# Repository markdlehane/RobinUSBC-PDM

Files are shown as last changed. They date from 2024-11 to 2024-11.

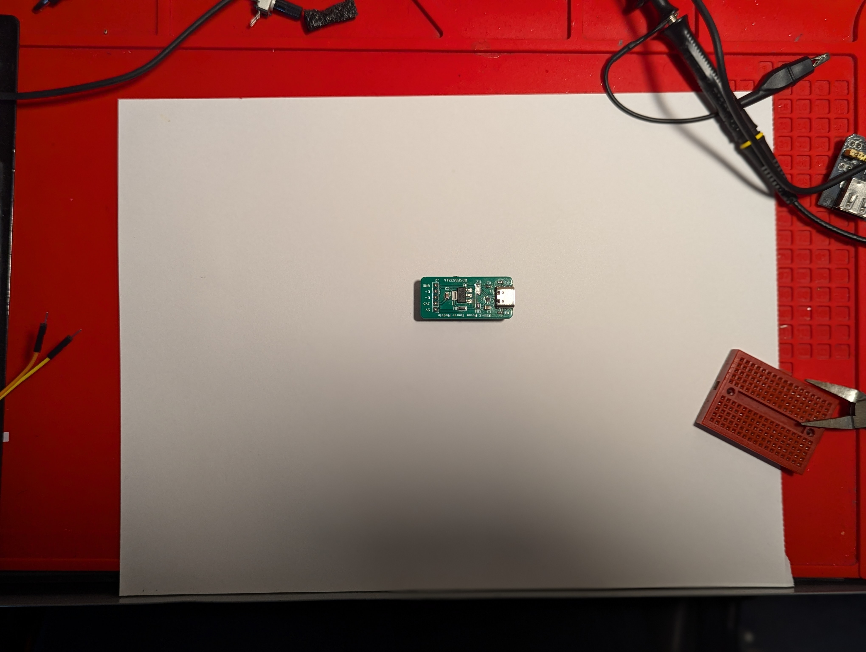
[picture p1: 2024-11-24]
NonGit/Media/PXL_20241114_141916100.PORTRAIT.jpg

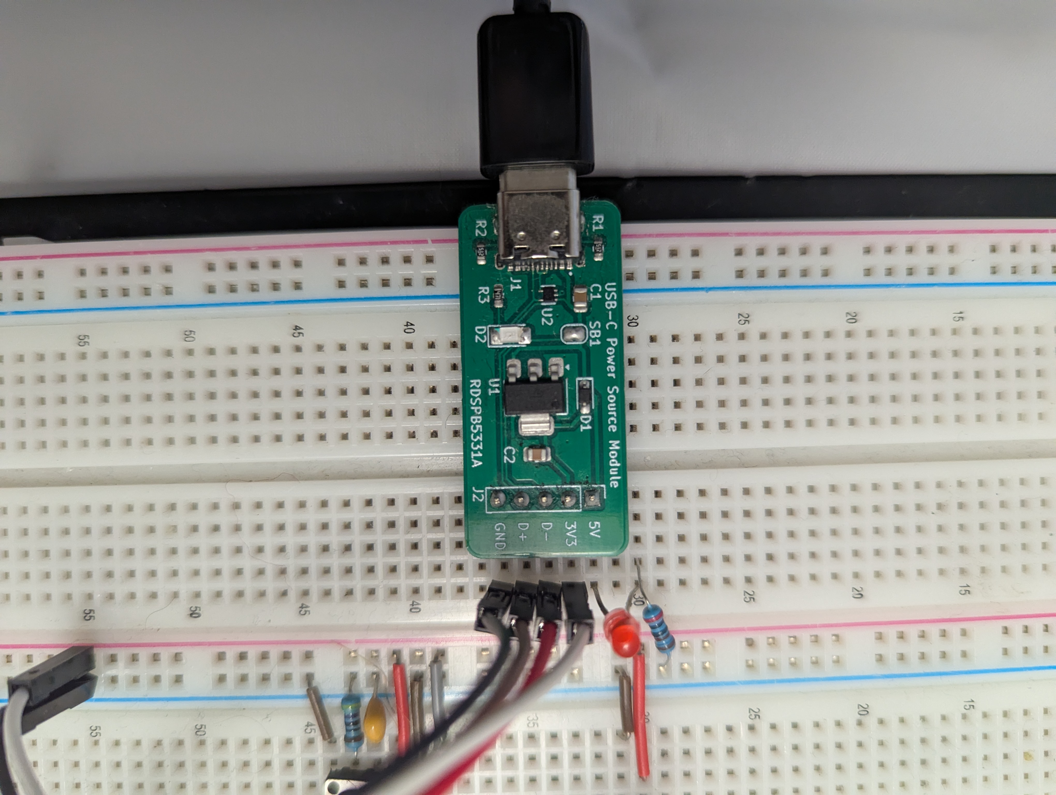
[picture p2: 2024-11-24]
NonGit/Media/PXL_20241124_145701699.RAW-01.COVER.jpg

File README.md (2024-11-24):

# USB-C data and power supply.

## An adaptor that allows connection from a usb power supply or laptop.
RDSPB5331A-Circuit

It's available as a kit or a premade module on [Tindie](https://www.tindie.com/products/36667/).

This adaptor provides 5v & 3.3v @1A from a USB-C connector. It also provides USB D+ and D- pins so that it can be used with a laptop or computer to provide power and data. I developed this board with the assistance of the wonderful people at [PCBWay](https://www.pcbway.com/) who enabled me to take my early design and turn it into a module that I use in every project I make now.  It's a huge time saver and makes the process of connecting my development boards to a laptop, very simple.

## Why did you make it?

I designed this module because I was tired of the standard breadboard power supplies that simply provide 5v or 3.3v from a barrel jack. The old style supplies were limited because, even if I use USB as a supply, I didn't have a data connection. 

## What makes it special?

This module is easy to use on a breadboard, can be integrated directly into a PCB project with a jumper and provides a data pathway to your embedded device. There is a transient voltage suppression device on the board to give added project from voltage spikes as the cable is connected.

## Module design

I designed this board because I have been developing project with ESP32S3 modules. These made a USB data connection immediately available, like many other alternatives, and I wanted to simplify my prototyping and development process through simplification. 

The module is supplied with an [AZ1117I](https://www.diodes.com/assets/Datasheets/AZ1117I.pdf) 3.3v LDO and the 5v is provided directly by the USB-C connection (which uses 2 5k1 1% resistors to negotiate the voltage). There is an LED on the board to indicate that 5v power is connected by this can be disconnected through a solder bridge so that it can be disabled when power must be stricly controlled.

RobinUSBC-back-PSM
RobinUSBC-Front-PSM

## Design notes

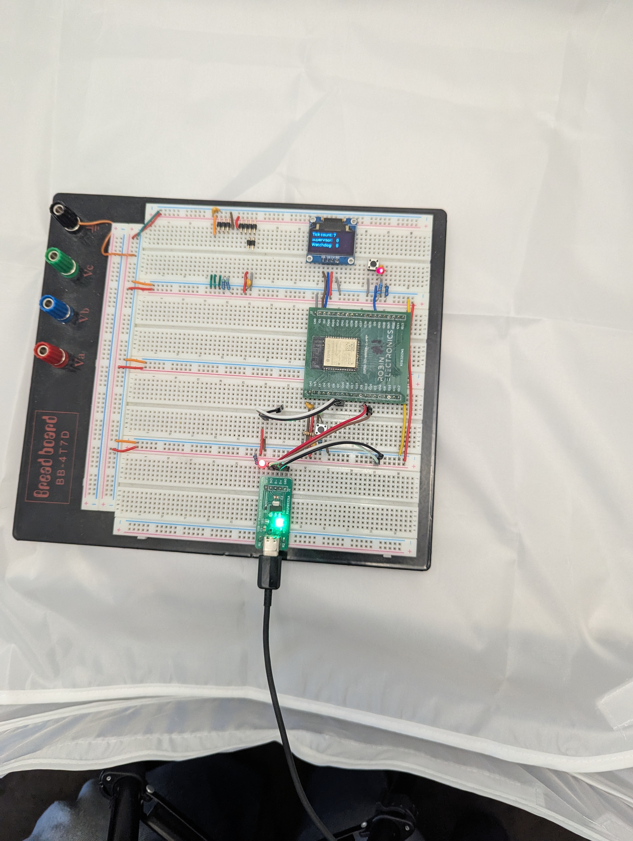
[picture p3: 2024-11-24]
NonGit/Media/PXL_20241124_145235331.RAW-01.COVER.jpg

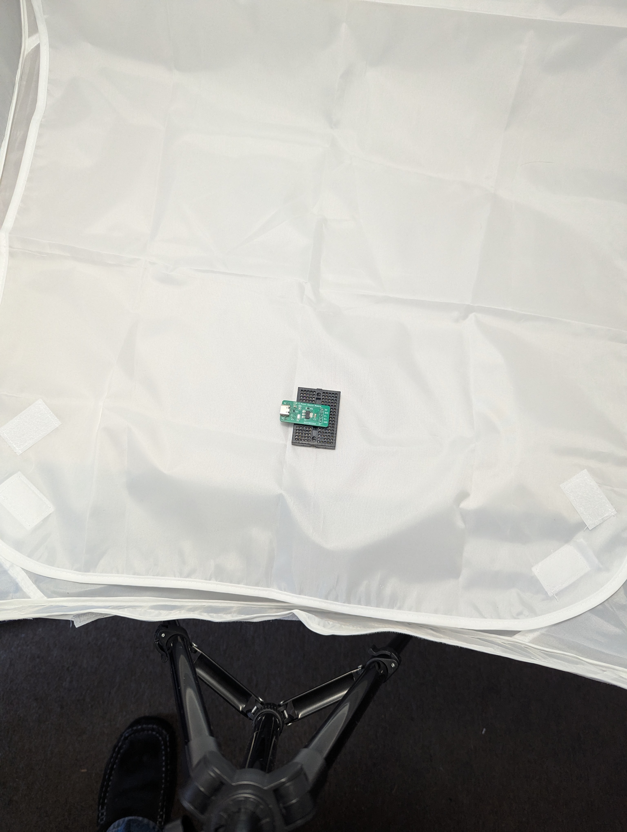
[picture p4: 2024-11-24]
NonGit/Media/PXL_20241124_144541206.RAW-01.COVER.jpg

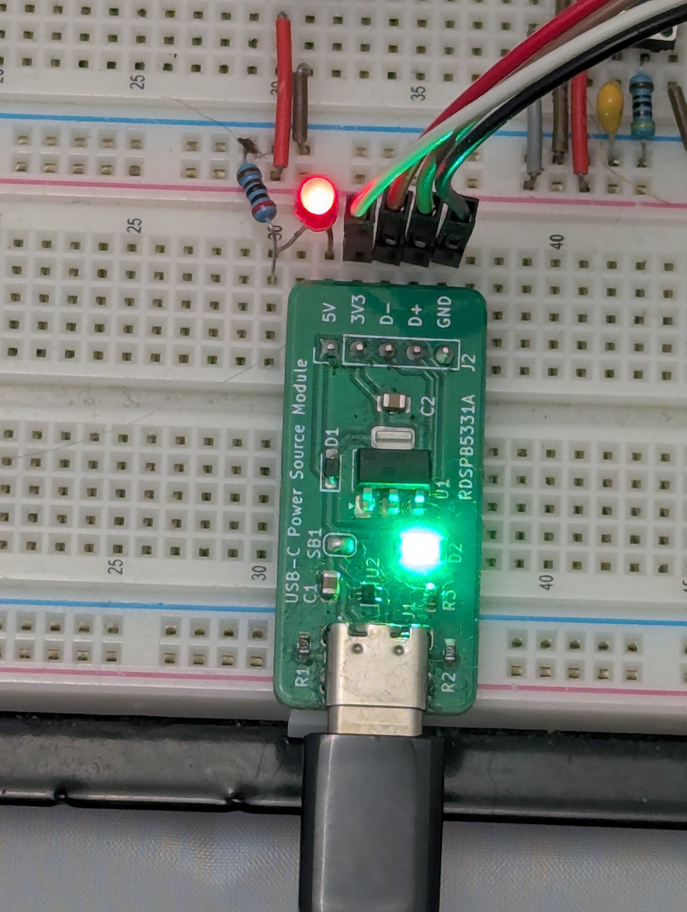
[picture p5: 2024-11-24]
NonGit/Media/PXL_20241124_144733794.RAW-01.COVER.jpg

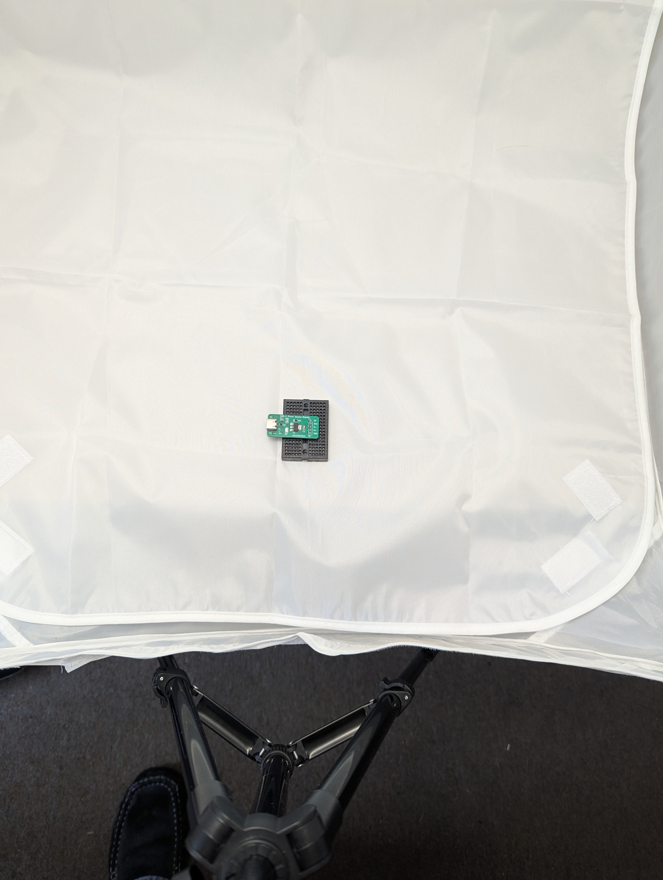
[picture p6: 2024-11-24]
NonGit/Media/PXL_20241124_144548405.RAW-01.COVER.jpg

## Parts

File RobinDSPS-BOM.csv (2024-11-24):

Reference | Value | Description | PartNo | MANUFACTURER
C1 | 10uF | 10 µF ±10% 16V Ceramic Capacitor X7R 0805 (2012 Metric) | CL21B106KOQNNNE | Samsung Electro-Mechanics
U1 | AZ1117IH-3.3TRG1 | 1A 20V Fixed LDO Linear Regulator, 3.3V, SOT-89/SOT-223/TO-220/TO-252/TO-263 | AZ1117IH-3.3TRG1 | Diodes Incorporated
R3 | 1K | 1k 0604 Resistor | RC0603JR-071KL | YAGEO
R1 | 5K1 | 5K1 0603 Resistor | RC0603FR-075K1L | YAGEO
R2 | 5K1 | 5K1 0603 Resistor | RC0603FR-075K1L | YAGEO
C2 | 22uF | CAP CER 22UF 10V X7R 0805 | GRM21BZ71A226ME15L | Murata Electronics
J1 | USB4215-03-A_REVA | CONN RCP USB2.0 TYP C 24P SMD RA | USB4105-GF-A-060 | Global Connector Technology
J2 | Power Output | Connector Header Through Hole 10 position 0.100" (2.54mm) | PH1-10-UA | Adam Tech
D2 | RED LED | LED RED CLEAR 1206 SMD | 150120RS75000 | WÃ¼rth Elektronik
D1 | NSR0530HT1G | Schottky diode, 30V, 500mA | NSR0530HT1G | onsemi
U2 | NUP2114 (TVS) | TVS Protection Diode | NUP2114UPXV5T1G | Diodes Incorporated

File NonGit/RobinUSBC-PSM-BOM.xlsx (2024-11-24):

Robin USBC-PSM Build Notes
Date | 2024-10-17 |  | Specification | 5v & 3.3v output @ up to 1A, with USB data lines.
Model |  | RDSPB5331A
Bill of Materials
Pick Order | Reference | Value | Footprint | Description
5 | C1 | 10uF | 0805 | 10 ÂµF Â±10% 16V Ceramic Capacitor X7R 0805 (2012 Metric)
6 | C2 | 22uF | 0805 | CAP CER 22UF 10V X7R 0805
7 | D1 | NSR0530HT1G | SOD-323 | Schottky diode, 30V, 500mA
8 | D2 | RED LED | 1206 | LED RED CLEAR 1206 SMD
10 | J1 | USB4215-03-A_REVA | GCT_USB4215-03-A_REVA | CONN RCP USB2.0 TYP C 24P SMD RA
11 | J2 | Power Output | Pin Header | Connector Header Through Hole 10 position 0.100" (2.54mm)
2 | R1 | 5K1 | 0603 | 5K1 0603 Resistor
3 | R2 | 5K1 | 0603 | 5K1 0603 Resistor
4 | R3 | 470R | 0603 | 470R 0604 Resistor
9 | U1 | AZ1117IH-3.3TRG1 | SOT-223-3 | 1A 20V Fixed LDO Linear Regulator, 3.3V, SOT-89/SOT-223/TO-220/TO-252/TO-263
1 | U2 | NUP2114 (TVS) | SOT-553 | TVS Protection Diode
Pick and Place List
Pick Order | Reference | Value | Footprint | Description
1 | U2 | NUP2114 (TVS) | SOT-553 | TVS Protection Diode
2 | R1 | 5K1 | 0603 | 5K1 0603 Resistor
3 | R2 | 5K1 | 0603 | 5K1 0603 Resistor
4 | R3 | 470R | 0603 | 470R 0604 Resistor
5 | C1 | 10uF | 0805 | 10 ÂµF Â±10% 16V Ceramic Capacitor X7R 0805 (2012 Metric)
6 | C2 | 22uF | 0805 | CAP CER 22UF 10V X7R 0805
7 | D1 | NSR0530HT1G | SOD-323 | Schottky diode, 30V, 500mA
8 | D2 | RED LED | 1206 | LED RED CLEAR 1206 SMD
9 | U1 | AZ1117IH-3.3TRG1 | SOT-223-3 | 1A 20V Fixed LDO Linear Regulator, 3.3V, SOT-89/SOT-223/TO-220/TO-252/TO-263
10 | J1 | USB4215-03-A_REVA | GCT_USB4215-03-A_REVA | CONN RCP USB2.0 TYP C 24P SMD RA
11 | J2 | Power Output | Pin Header | Connector Header Through Hole 10 position 0.100" (2.54mm)
Build Notes
Pick Order | Reference
10 | J1 | Ensure Solder is placed in ground lugs to support multiple insertion / removal of USB-C plug.
11 | J2 | Place after other components have been soldered on hotplate.
Confirmation of Pick & Place
Pick Order | Reference | Value | Picked | Placed?
1 | U2 | NUP2114 (TVS) | o | o
2 | R1 | 5K1 | o | o
3 | R2 | 5K1 | o | o
4 | R3 | 470R | o | o
5 | C1 | 10uF | o | o
6 | C2 | 22uF | o | o
7 | D1 | NSR0530HT1G | o | o
8 | D2 | RED LED | o | o
9 | U1 | AZ1117IH-3.3TRG1 | o | o
10 | J1 | USB4215-03-A_REVA | o | o
11 | J2 | Power Output | o | o

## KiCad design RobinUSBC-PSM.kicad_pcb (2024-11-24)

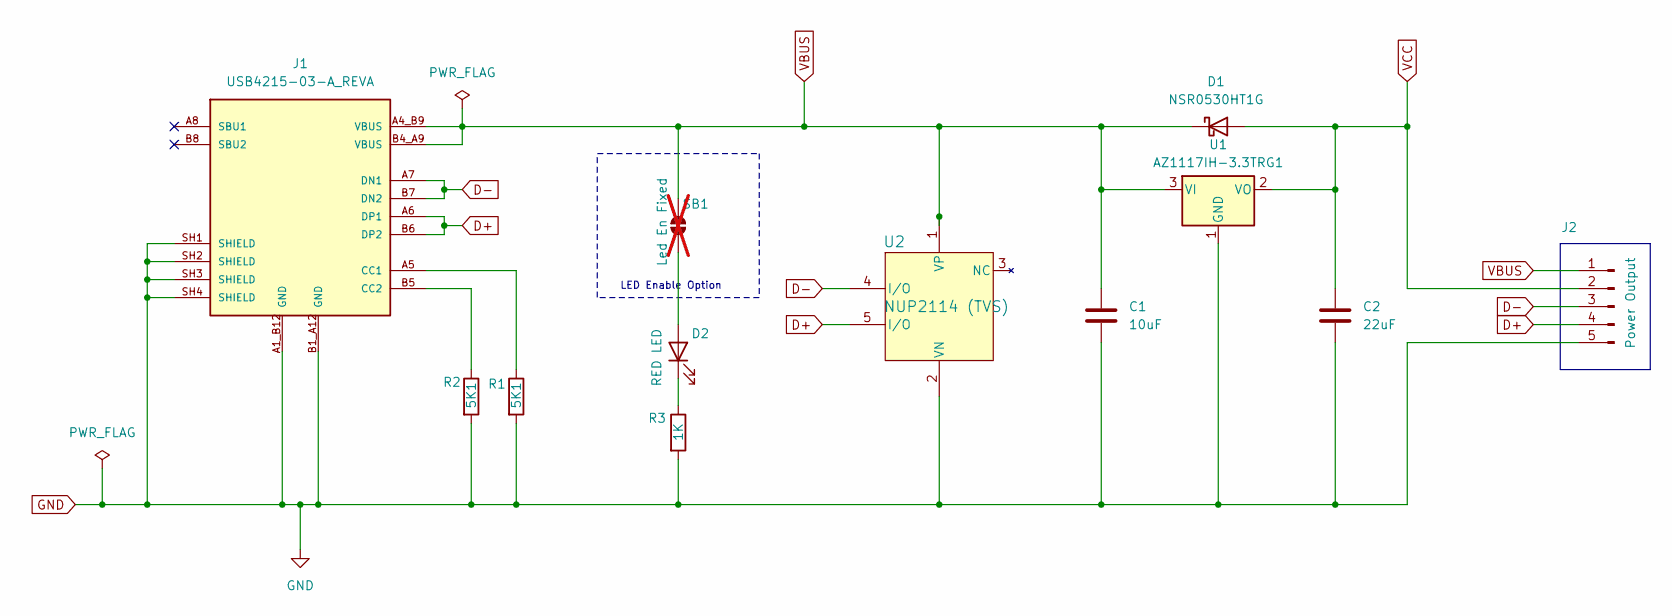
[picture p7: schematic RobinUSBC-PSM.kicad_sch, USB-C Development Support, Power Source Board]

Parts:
C1: 10uF; C_0805_2012Metric; PartNo CL21B106KOQNNNE
C2: 22uF; C_0805_2012Metric; PartNo GRM21BZ71A226ME15L
D1: NSR0530HT1G; D_SOD-323_HandSoldering; PartNo NSR0530HT1G
D2: RED LED; D_1206_3216Metric_Pad1.42x1.75mm_HandSolder; PartNo 150120RS75000
J1: USB4215-03-A_REVA; GCT_USB4215-03-A_REVA; PARTREV A; DigiKey_Part_Number 2073-USB4215-03-ATR-ND
J2: Power Output; PinHeader_1x05_P2.54mm_Vertical; PartNo PH1-10-UA
R1, R2: 5K1; R_0603_1608Metric; PartNo RC0603FR-075K1L
R3: 1K; R_0603_1608Metric; PartNo RC0603JR-071KL
SB1: Led En Fixed; SolderJumper-2_P1.3mm_Open_RoundedPad1.0x1.5mm; PartNo Solder Jumper, 2-pole, open; not fitted
U1: AZ1117IH-3.3TRG1; SOT-223-3_TabPin2; PartNo AZ1117IH-3.3TRG1
U2: NUP2114 (TVS); SOT-553_1P65X1P25_ONS; PartNo NUP2114UPXV5T1G

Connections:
D+: J1.A6 (DP1), J1.B6 (DP2), J2.4, U2.5 (I/O)
D-: J1.A7 (DN1), J1.B7 (DN2), J2.3, U2.4 (I/O)
GND: C1.2, C2.2, J1.A1_B12 (GND), J1.B1_A12 (GND), J1.SH1 (SHIELD), J1.SH2 (SHIELD), J1.SH3 (SHIELD), J1.SH4 (SHIELD), J2.5, R1.2, R2.2, R3.2, U1.1 (GND), U2.2 (VN)
unnamed: D2.2 (A), SB1.1 (A)
unnamed: D2.1 (K), R3.1
unnamed: J1.A5 (CC1), R1.1
unnamed: J1.B5 (CC2), R2.1
VBUS: C1.1, D1.1 (K), J1.A4_B9 (VBUS), J1.B4_A9 (VBUS), J2.1, SB1.2 (B), U1.3 (VI), U2.1 (VP)
VCC: C2.1, D1.2 (A), J2.2, U1.2 (VO)

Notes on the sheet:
LED Enable Option

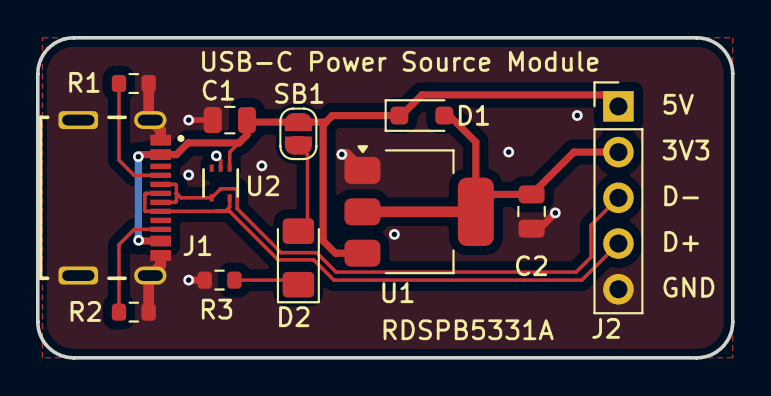
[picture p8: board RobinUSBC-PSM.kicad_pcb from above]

Board: 2 copper layers, 38.6 x 17.8 mm, 12 parts (0 on the bottom side), 9 nets.

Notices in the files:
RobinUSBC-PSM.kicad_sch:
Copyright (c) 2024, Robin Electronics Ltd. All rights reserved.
